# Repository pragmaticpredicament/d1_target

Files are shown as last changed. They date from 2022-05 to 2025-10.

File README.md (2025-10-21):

This repo documents an inexpensive reactive and dynamic target system, with a configurable and easy to use interface.

Demo 1

Demo 2

The d1 mini is ideally suited to this task
* cheap
* built in wifi (for target communications)
* enough i/o pins for 2 sets of leds
* enough i/o drive current for daylight bright leds without additional driver components

# Bill of materials (per target)
### power supply:
* 2xaa battery box - https://www.ebay.com/itm/274488658276
* ~~usb pigtail (to plug into d1 mini) - https://www.ebay.com/itm/193849305502~~ (I just directly solder the boost converter to the d1 mini now, bypassing this point of failure)
* boost converter (to convert to 5v) - https://www.ebay.com/itm/143853151565

### target:
* WeMos D1 Mini ESP8266 Arduino WiFi Board
* ADXL345 accelerometer - https://www.ebay.com/itm/114721937607
* common annode 4 color leds (clear seems brighter head on vs diffuse, common annode allows more current)- ~~https://www.ebay.com/itm/274488658276~~ I just search "5MM 4pin Common Anode Water Clear RGB" on ebay
* resistors (I chose 100 ohms for red, 220 ohms for green, and 50 ohms for blue)
* ~~connectors to make replacing broken leds easier (I used 4 pin jst sm connectors) - https://www.ebay.com/itm/274534656436~~ (I have stopped using these, I just hardwire all leds now. They haven't proven to be worth the hassle)
* extra wire, solder, heat shrink etc.. to connect everything together

### additional:
* wifi router ( i use GL.iNet GL-AR300M16-Ext https://www.amazon.com/dp/B07794JRC5)
* smartphone/computer to connect to targets and run game

# Build Instructions

### Wiring Diagram:
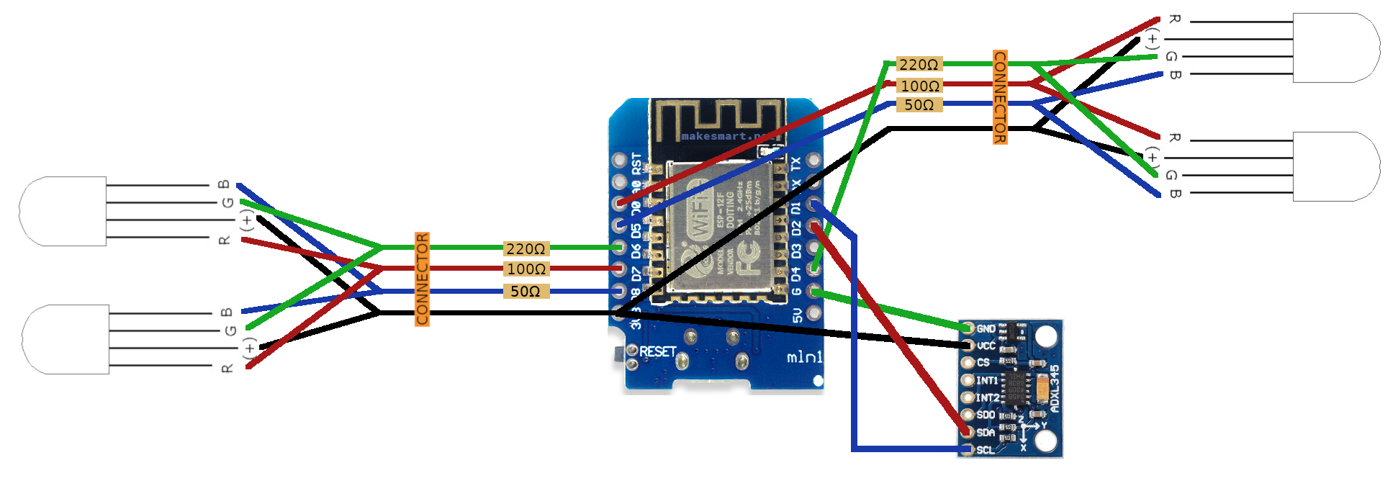
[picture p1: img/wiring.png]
Wiring Diagram


### Assembly:
You can arrange your components however you want. It was convenient for me to attach the d1 mini and the boost converter to the battery conatiner:

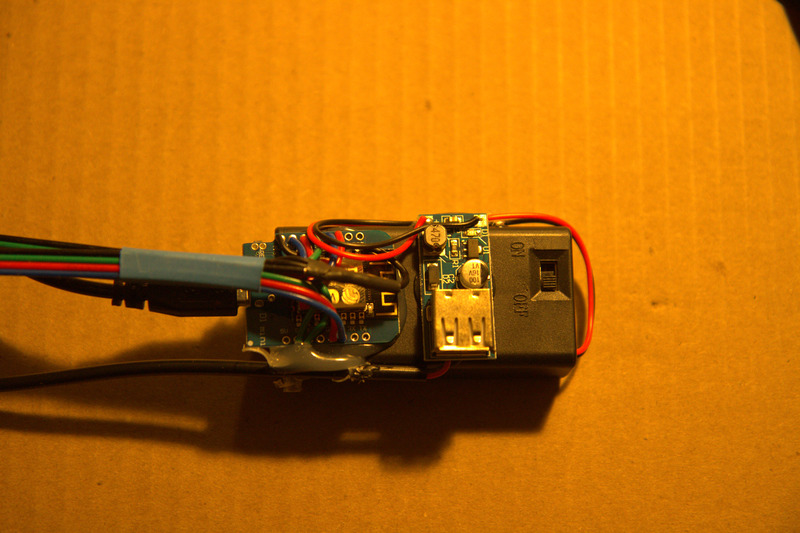
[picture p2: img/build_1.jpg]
Build 1

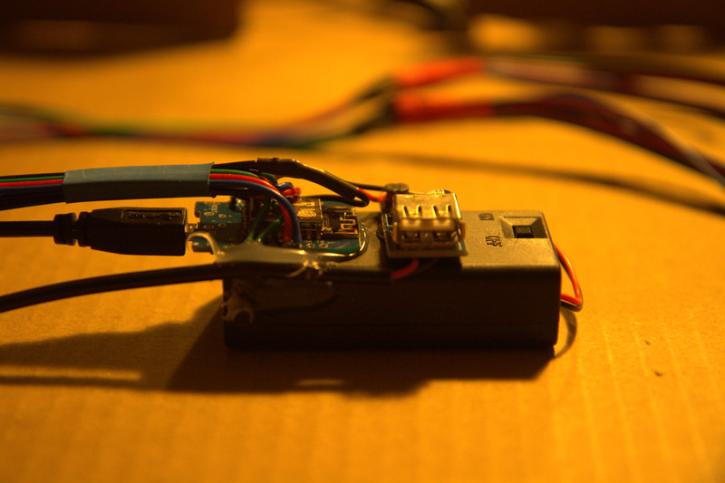
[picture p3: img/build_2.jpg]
Build 2

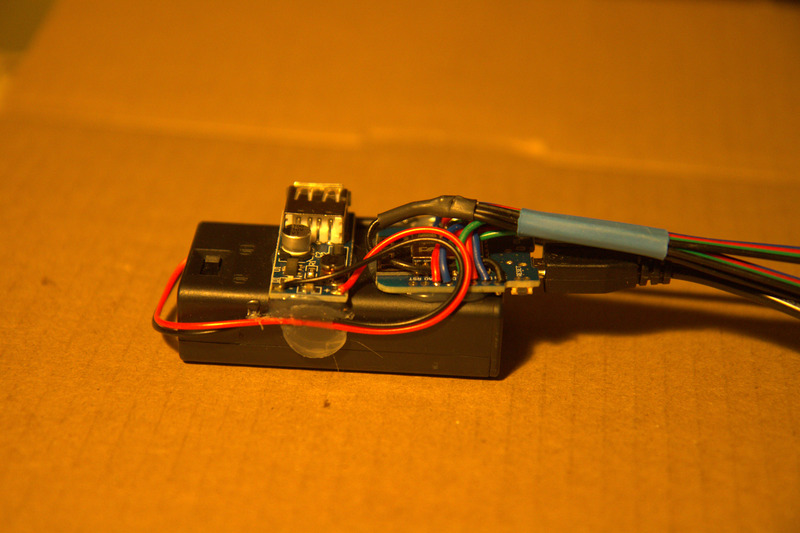
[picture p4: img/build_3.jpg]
Build 3


I left the leds and accelerometers a bit long 

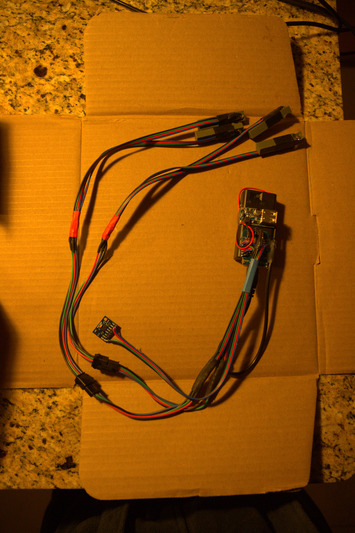
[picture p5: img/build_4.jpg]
Build 4


I use these little led brackes to help secure the leds.
* led_bracket.stl in /stl 
* I manually drilled them out with a 1/8 drill for the leds to fit

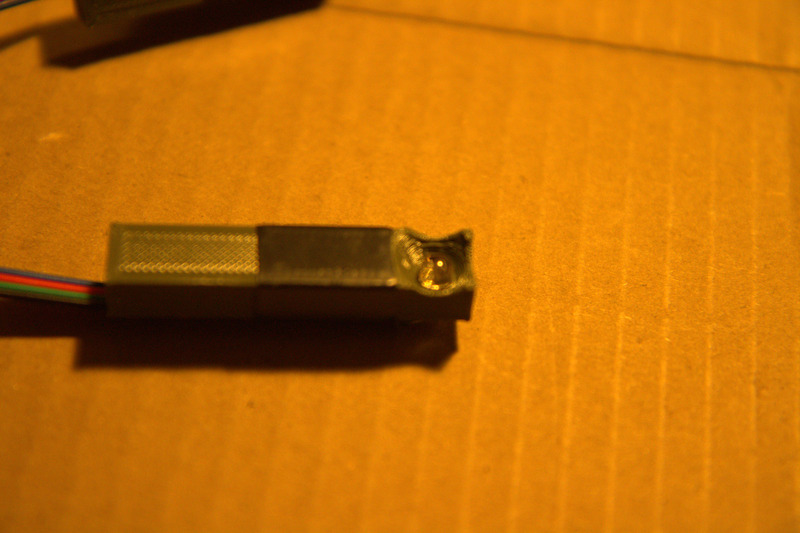
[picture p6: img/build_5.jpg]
Build 5

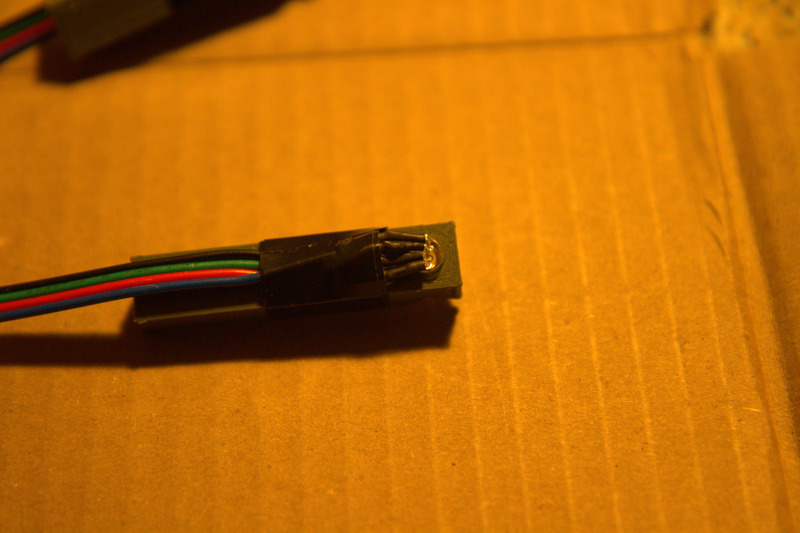
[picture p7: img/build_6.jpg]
Build 6


Here you can see how they are attached to the target, with the accelerometer taped to the center, and the leds just slightly protruding

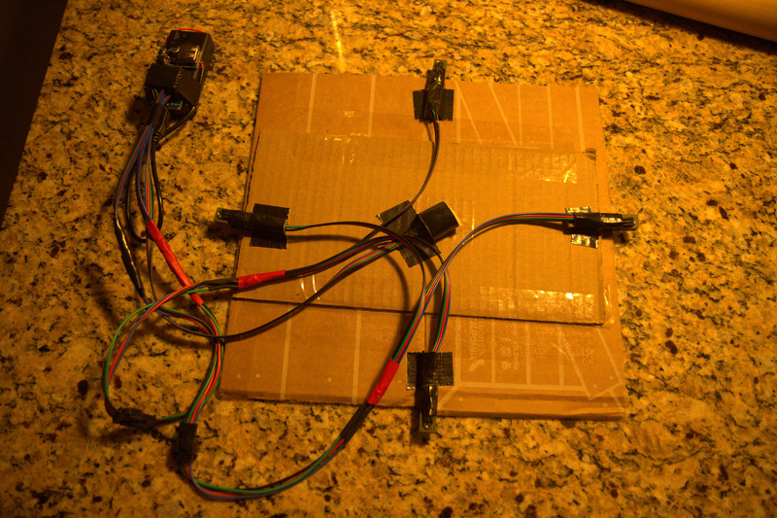
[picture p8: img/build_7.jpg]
Build 7


# Ide setup:

### Arduino/d1 mini setup: https://gist.github.com/carljdp/e6a3f5a11edea63c2c14312b534f4e53
* install latest arduino release https://www.arduino.cc/en/software/OldSoftwareReleases (or use ubuntu software repo)
* add board manager url: File -> preferences -> Additional Boards Manager URLs : http://arduino.esp8266.com/stable/package_esp8266com_index.json
* install d1 mini board: Tools -> Board:* -> Boards Manager... : install esp8266 (3.0.2 at time of writing)
* select d1 mini board: Tools -> Board:* -> ESP8266 Boards (3.0.2) -> LOLIN(WEMOS) D1 mini (clone)
* plug in d1 mini
* update port: Tools -> Port
* you can test this part of the setup by running the blink sketch, described in the above linked walkthrough

### adxl345 setup: https://www.teachmemicro.com/use-adxl345-arduino/
* from Tools -> Manage Libraries..., install “Adafruit ADXL345” (1.3.1 at time of writing), install all dependencies

### filesystem uploader: https://randomnerdtutorials.com/install-esp8266-filesystem-uploader-arduino-ide/
* unzip https://github.com/esp8266/arduino-esp8266fs-plugin/releases into tools folder
* for ubuntu repository arduino install, path was ~/snap/arduino/61/Arduino/tools/ESP8266FS/tool/esp8266fs.jar 
* for installing arduino outside of repository, path was ~/Arduino/arduino-1.8.15/tools/ESP8266FS/tool/esp8266fs.jar
* your path may be different, you can find the genral location from File -> Preferences : Sketchbook Location
You must restart arduino for the uploader to show up 
* uploader will be at Tools -> ESP8266 Sketch Data Upload

### Your IDE environment is now set up

# Send software to d1 mini:
* The project folder (git checkout dir) must be named d1_target
* In the Arduino IDE, Open d1_target.ino (the parent folder must also be named d1_target)
* Click Verify (Check mark below File)
* Click Upload (Right Arrow below Edit)
* Upload website data to d1 mini: Tools -> ESP8266 Sketch Data Upload (make sure any serial monitors are closed)

### d1 target software should now be on the d1 mini

# Wifi router setup
* the default ssid that the d1 mini targets will try to connect to is "TARGET_NET", and the password is "d1miniii"
  * you should set your router to those parameters, or update the parameters "ssid" and "wpass" in d1_target.ino (and then re upload) 
* targets are detected basically by a ping sweep, so limiting the dhcp address range helps if possible
* having a portable router that can run off a usb battery pack helps if you are moving your targets outside of the house

# Testing

### Obtain IP Address:
* when the target is able to connect to wifi, and get an ip address, all 4 leds will turn green (and stay green until given another command)
* you need to obtain the ip address of your d1 mini. this can be done in several ways:
  * you can use the arduino serial monitor (Tools -> Serial Monitor, use 115200 baud) then plug the target into your usb cable.  after the target boots up and gets an ip connection, it will output the ip address
  * use your wifi router interface to find the ip address from a client list
  * manually start testing ip addresses starting at your router's dhcp address range

### Run a blink command:
* `curl 'http://<ip address>/blink?count=3&on=500&off=500&color=r'`
  * All 4 leds should blink red 3 times
* `curl 'http://<ip address>/blink?count=3&on=500&off=500&color=g'`
  * All 4 leds should blink green 3 times
* `curl 'http://<ip address>/blink?count=3&on=500&off=500&color=b'`
  * All 4 leds should blink blue 3 times
* `curl 'http://<ip address>/blink?count=3&on=500&off=500&color=w'`
  * All 4 leds should blink white 3 times
* curl command should return `{"blinked":true}`

### Run a target command
* `curl 'http://<ip address>/target?x=20&y=20&z=20&duration=10000'`
  * All 4 leds should turn blue for 10 seconds (duration value=milliseconds) then turn red
  * your curl command should return something like this:
`{"x":0,"y":0,"z":0,"hit_time":0.00,"hit_interval":0,"max_interval":1552,"sample_interval":1250,"samples":8002,"expected_samples":8001}`
  * x, y, and z are the maximum g force (in 10ths of a g) that was experienced by the accelerometer during the target command

### Interact with target: 
* `curl 'http://<ip address>/target?x=20&y=20&z=20&duration=10000'`
  * All 4 leds should turn blue. Flick the accelerometer within 10 seconds (duration = milliseconds), All leds should turn green
  * Your curl command should return something like this:
`{"x":10,"y":9,"z":73,"hit_time":874.00,"hit_interval":1249,"max_interval":1531,"sample_interval":1250,"samples":701,"expected_samples":700}`
  * x, y, and z should be nonzero, and scale relative to how hard the accelerometer was flicked

### Load Web UI

### If all of these work, you can safely assume that this target is tested working

# Gameplay:

### Load the game interface in a web browser
* You will need to open a web browser on your smartphone, laptop, etc.. that is connected to the same network as the target.
* go to one of the addresses of your targets.  Each target will have the web page code, so you only need to find one of them.
  * I personally just manually type in the first address of the dhcp range I have set up in my router, then manually increment until I hit one.
  * You can also find the ip of one of the targets by connecting it to the serial arduino monitor

## There are 3 sections of the ui:

### Target Setup
The first section of the UI detects the targets.

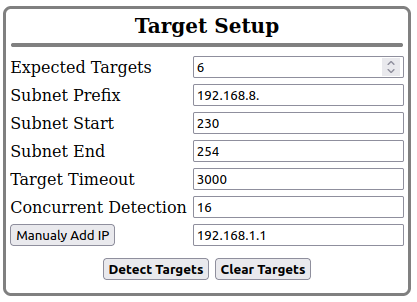
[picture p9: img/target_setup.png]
Target Setup


* Expected Targets: This represents how many targets you expect to be detected (how many are currently on, with green lights indicating they have an ip address)
* Subnet Prefix/Subnet Start/Subnet End: this defines the range to be scanned for targets
  * In this case we will scan 192.168.8.230 - 192.168.8.854
  * This should generally correspond with the dhcp address range you have configured on your wifi router
* Target Timeout: How long to wait for each target to respond
* Concurrent Detection:  How many targets should be pinged at a time
* Manually Add IP: If you want to manually type in ip addresses
* Detect Targets: Scan the ip address range above using the timeouts, and add targets as they respond
* Clear Targets: Clear any targets that have been found

Once target detection or manual addition is complete, you should see the targets listed

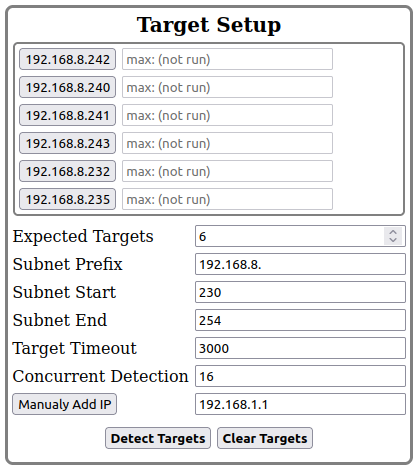
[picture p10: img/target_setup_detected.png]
Target Setup Detected


* Each ip address is a clickable button that will cause the corresponding target to light up blue for 3 seconds, then return the maximum g force the target experienced while light.

### Stage Setup
Your gameplay consists of multiple actions linked together to form a stage. You can use the plus and minus buttons to add or remove actions.

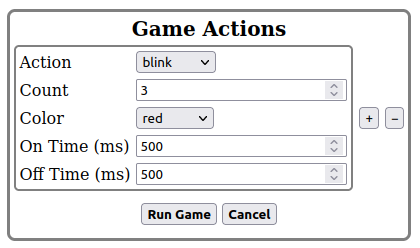
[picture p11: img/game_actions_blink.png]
Game Actions Blink


Action: Blink - This action will blink all targets, at the same time, with the specified parameters.
* Count: The number of times each target should blink
* Color: The color of the leds that should be set during the blinks
* On Time (ms): The amount of time each led should stay on per blink, in milliseconds
* Off Time (ms): The amount of time each led should stay off per blink, in milliseconds

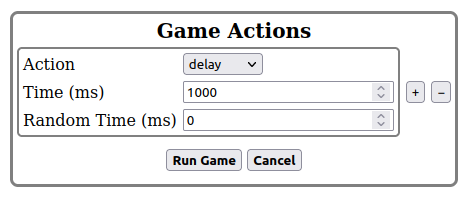
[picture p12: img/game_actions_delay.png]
Game Actions Delay


Action: Delay - This action will insert a delay between other actions equal to (Time + (between 0 and Random Time)) milliseconds.
* Time (ms): The amount of time that this action will delay
* Random Time (ms): An additional maximum random delay added to the fixed above delay (random value between 0 and this value)

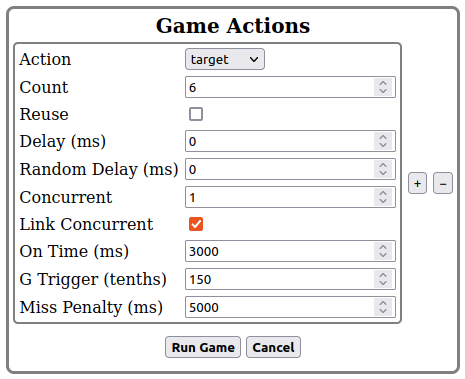
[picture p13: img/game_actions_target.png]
Game Actions Target


Action: Target - this causes targets to be available to be hit
* Count: The total number of targets that will be available to be hit during this action
* Reuse: If a target can be light more than once during this action
  * targets are picked randomly, if reuse is enabled, then a target, once light, will go back into the random selection pool
  * if not enabled, only min(count, existant targets) can be light, because the random target selector will not consider a target again after it has been light
* Delay (ms): The delay between each target being light and available to be hit.
* Random Delay (ms): An additional maximum random delay (random value between 0 and this value)
* Concurrent: How many targets to light concurrently
* Link Concurrent: Should all concurrent targets have to be hit before new targets can be light
* On Time (ms): Amount of time the target will be light before either being hit, or considered a failure
* G Trigger (tenths): How hard you need to hit the target to register (140 = 14.0 g)
* Miss Penalty (ms): How much time should be added to your score should you fail to hit the target in the alloted time 

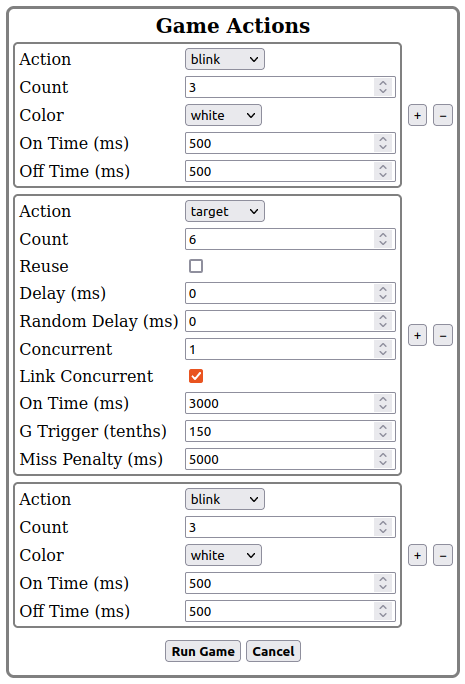
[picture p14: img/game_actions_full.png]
Game Actions Full


Here is our sample game:
* We blink white 3 times, to indicate to the player that the stage is beginning
* Each of our 6 targets will be light once, in a random ordering
  *The Player gets 3 seconds to hit the target before it is considered a failure

The target UI works as such:
* A target lights up blue, indicating that it is available to be hit
* If the target is hit before the time limit expires, the target turns green, and another target is light (if any more are available)
* If the target expires before being hit, the target turns red, and another target is light (if any more are available)

## Game Results
Game results are broken down into sections. 
* The first section is the overall summed results of all target actions
* Subsequent sections give the results of each action individually

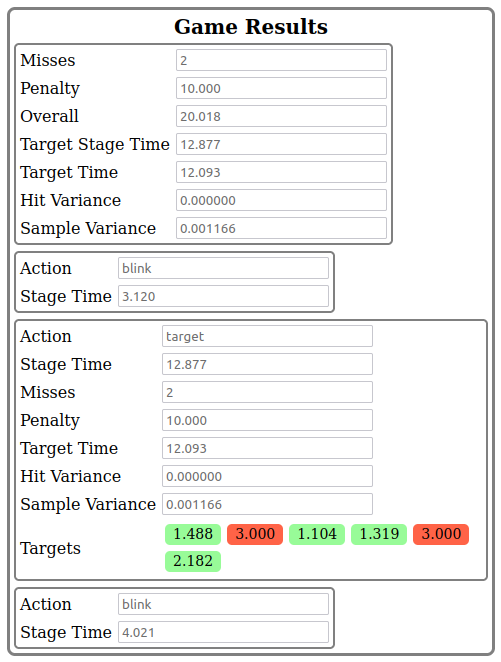
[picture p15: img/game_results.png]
Game Results


### Target Actions Summary
* Misses: The total misses of all target actions
* Penalty: The total penalties accrued over all target actions 
* Overall: The total time to complete all actions
* Target Stage Time: The total time to complete all target actions
* Target Time: The total time that each target was blue, before being hit or timing out (as measured on the target)
  * In my opinion this is the most fair and valuable score, as it is not effected by any network latency
* Hit Variance: This is mostly a debug parameter.  It indicates the maximum time error during the iteration on the d1 mini during which the hit was detected
* Sample Variance: This is mostly a debug parameter.  It indicates the sumation of all time error on sampling intervals for the d1 min.
  * Time error exists in this project as the d1 mini requires the programmer to yeild time to it to handle the tcp/ip stack, and this time is non deterministic. 

### Individual Actions 
* For blink and delay actions, these just display the time information that each action consumed
* For target actions, the metrics are similar to the summary above, with the addition of timing information for each individual target.

# Design notes
The d1 mini i/o pins are documented to provide 12ma max, however it supposedly can provide up to 15ma if you use the i/o pins to provide grounds to the leds, which is why I use common annode leds 

Here is the led characterization i got for various resistor configurations using the d1 mini i/o output voltage (for ~~https://www.ebay.com/itm/274488658276~~ search "5MM 4pin Common Anode Water Clear RGB" on ebay)
I tested both single leds, and 2 leds in parallel (which is the configration used in this project

|Leds in parallel|resistor ohms|Red ma|Green ma|Blue ma|
|---|---|---|---|---|
|1|50|13|7|6|
|1|100|23|11|10|
|1|220|7|4|4|
|2|50|26|14|12|
|2|100|14|9|7|
|2|220|7|5|4|

For 2 leds in parallel, the following resistor values provided the maximum output, while staying under the maximum 15ma current, and appearing of similar brightness
* red: 100 ohms
* green: 220 ohms
* blue: 50 ohms

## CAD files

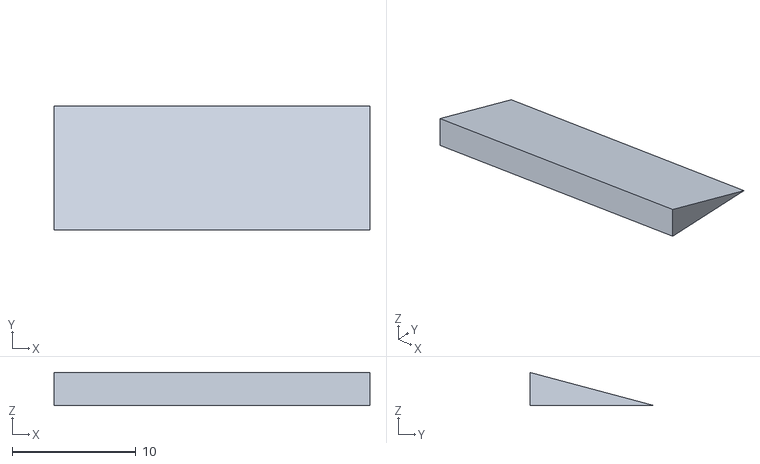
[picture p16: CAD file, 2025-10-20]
stl/15_degree_wedge.stl
25.5 x 10.0 x 2.67

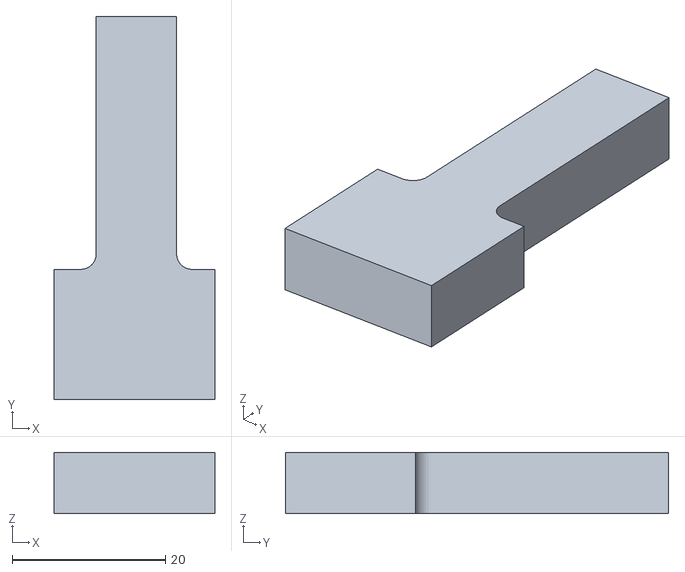
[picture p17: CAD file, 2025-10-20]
stl/accelerometer_strain_relief.stl
21.0 x 50.0 x 8.00

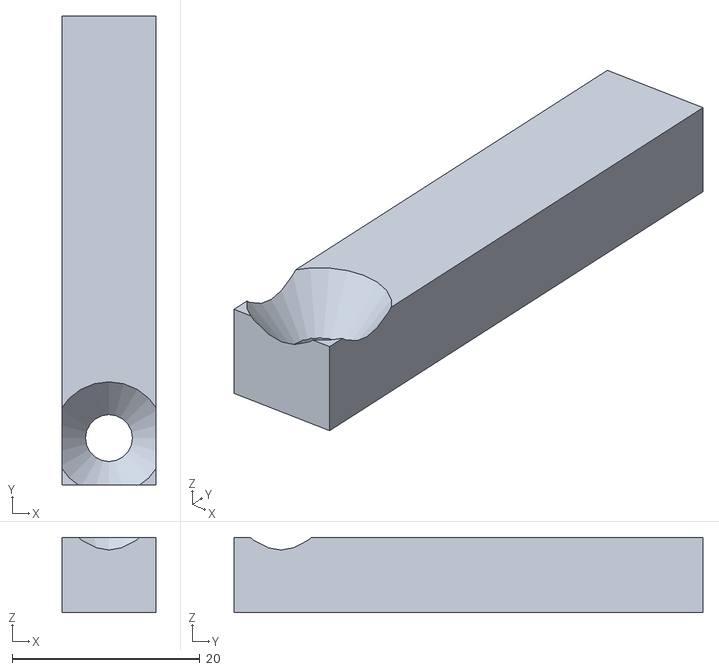
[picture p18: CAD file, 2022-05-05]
stl/led_bracket.stl
10.0 x 50.0 x 8.00

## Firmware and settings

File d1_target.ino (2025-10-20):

#include <ESP8266WiFi.h>
#include <ESP8266WebServer.h>
#include <Adafruit_ADXL345_U.h>
#include <Wire.h>
#include <FS.h>

const String version = "0.3.0";

typedef unsigned long micro_t;

Adafruit_ADXL345_Unified accel = Adafruit_ADXL345_Unified(12345);

ESP8266WebServer server(80);

const String ssid = "TARGET_NET";
const String wpass = "d1miniii"; //password 8 chars
const String wmode = "infra";

IPAddress local_IP(192,168,4,205);
IPAddress gateway(192,168,4,1);
IPAddress subnet(255,255,255,0);

#define LED_RED_1	  D0
#define LED_RED_2	  D7
#define LED_GREEN_1 D4
#define LED_GREEN_2 D6
#define LED_BLUE_1  D5
#define LED_BLUE_2  D8

void setLed(char c){
	digitalWrite(LED_BUILTIN, (c=='a' || c=='i') ? LOW : HIGH);
	
	if(c=='a'){
		c='w';
	}
	
	//'w' = white
	if(c=='w' || c=='r'){
		digitalWrite(LED_RED_1, LOW);
		digitalWrite(LED_RED_2, LOW);
	}else{
		digitalWrite(LED_RED_1, HIGH);
		digitalWrite(LED_RED_2, HIGH);
	}
	
	if(c=='w' || c=='g'){
		digitalWrite(LED_GREEN_1, LOW);
		digitalWrite(LED_GREEN_2, LOW);
	}else{
		digitalWrite(LED_GREEN_1, HIGH);
		digitalWrite(LED_GREEN_2, HIGH);
	}
	
	if(c=='w' || c=='b'){
		digitalWrite(LED_BLUE_1, LOW);
		digitalWrite(LED_BLUE_2, LOW);
	}else{
		digitalWrite(LED_BLUE_1, HIGH);
		digitalWrite(LED_BLUE_2, HIGH);
	}
}

//all
//internal
//white
//red
//green
//blue
void setLed(const String &s){
	if(s.isEmpty()){
		setLed('x');
	}
	setLed(tolower(s[0]));
}

void blinkLed(int count, int on, int off, String color){
	for(int i=0;i<count;++i){
		setLed('x');
		delay(off);
		setLed(color);
		delay(on);
	}
	setLed('x');
}

void handleBlink() {
	int blink_count=0;
	int blink_on=500;
	int blink_off=500;
	String blink_color="green";
	
	if(server.hasArg("count")){
		blink_count=server.arg("count").toInt();
	}
	if(server.hasArg("on")){
		blink_on=server.arg("on").toInt();
	}
	if(server.hasArg("off")){
		blink_off=server.arg("off").toInt();
	}
	if(server.hasArg("color")){
		blink_color=server.arg("color");
	}
	
	blinkLed(blink_count, blink_on, blink_off, blink_color);

	String json = "{\"blinked\":true,\"v\":\"" + version + "\"}\n";
	server.sendHeader("Access-Control-Allow-Origin", "*");
	server.send(200, "application/json", json);
}

void handleTarget() {
	float x_trigger = 40;
	float y_trigger = 40;
	float z_trigger = 40;
	int x_value = 0;
	int y_value = 0;
	int z_value = 0;
	micro_t run_duration = 1000000; //how long is the target available to be hit
	micro_t sample_interval = ceil(1000000 / 800);
	int sample_count = 0;
	int result_show = 1000; //time to show hit result/timeout (red/green)
	bool noshoot = false;
	int light_duration = run_duration; //how long led will be light (target may be hit after light goes out if run_duration > light_duration)
	String color = "blue";
	
	if(server.hasArg("duration")){
		run_duration=server.arg("duration").toInt()*1000;
		light_duration=run_duration;
	}
	if(server.hasArg("light")){
		light_duration=server.arg("light").toInt()*1000;
	}
	if(server.hasArg("noshoot")){
		noshoot = true;
	}
	if(server.hasArg("result_show")){
		result_show=server.arg("result_show").toInt();
	}
	if(server.hasArg("color")){
		color=server.arg("color");
	}
	if(server.hasArg("g")){
		x_trigger=y_trigger=z_trigger=server.arg("g").toFloat();
	}
	if(server.hasArg("x")){
		x_trigger=server.arg("x").toFloat();
	}
	if(server.hasArg("y")){
		y_trigger=server.arg("y").toFloat();
	}
	if(server.hasArg("z")){
		z_trigger=server.arg("z").toFloat();
	}
	
	sensors_event_t event;
	micro_t rollover_addition = 0;
	micro_t start = micros();
	micro_t last = start;
	micro_t bucket = start / sample_interval;
	micro_t hit_time = 0;
	micro_t hit_interval = 0;
	micro_t max_interval = 0;
	
	setLed(color);
	while(true){
		micro_t curr = micros();
		accel.getEvent(&event);
		++sample_count;
		if(curr < start){
			rollover_addition = std::numeric_limits<micro_t>::max() - start;
			start = 0;
		}
		micro_t curr_offset = (curr - start) + rollover_addition;
		if( (curr_offset/1000) > light_duration ) {
			setLed('x');
		} 
		bucket = curr / sample_interval;
		
		if(abs(event.acceleration.x) > x_trigger
					|| abs(event.acceleration.y) > y_trigger
					|| abs(event.acceleration.z) > z_trigger ){
			hit_time= curr_offset;
			if(curr < last){
				 hit_interval = curr + (std::numeric_limits<micro_t>::max()-last);
			}else{
				 hit_interval = curr-last;
			}
			
			x_value = abs(floor(event.acceleration.x));
			y_value = abs(floor(event.acceleration.y));
			z_value = abs(floor(event.acceleration.z));
			break;
		}
		if(curr < last){
			max_interval = max(max_interval,curr + (std::numeric_limits<micro_t>::max()-last));
		}else{
			max_interval = max(max_interval,curr-last);
		}
		last = curr;
		
		if(((curr-start)+rollover_addition) >= run_duration){
		 	break;
		}
		
		yield(); //let esp8266 handle tcp/wifi
		curr = micros();
		if(curr < start){
			rollover_addition = std::numeric_limits<micro_t>::max() - start;
			start = 0;
		}

		micro_t curr_bucket = curr / sample_interval;
		if(curr_bucket == bucket){
			delayMicroseconds(sample_interval - curr%sample_interval);
		}
		bucket = micros() / sample_interval;
	} 
	String json;
	json += "{\"x\":" + String(x_value) + ",";
	json += "\"y\":" + String(y_value) + ",";
	json += "\"z\":" + String(z_value) + ",";
	json += "\"v\":\"" + version + "\",";
	json += "\"hit_time\":" + String(floor(hit_time/1000)) + ",";
   json += "\"hit_interval\":" + String(hit_interval) + ",";
	json += "\"max_interval\":" + String(max_interval) + ",";
	json += "\"sample_interval\":" + String(sample_interval) + ",";
	json += "\"samples\":" + String(sample_count) + ",";
	json += "\"expected_samples\":" + String((micros()-start)/sample_interval) + "}\n";
	server.sendHeader("Access-Control-Allow-Origin", "*");
	server.send(200, "application/json", json);
	if(noshoot){
		if(hit_time == 0){
			setLed('x');
		}else{
			blinkLed(5, result_show/10, result_show/10, "red");
		}
	}else{	
		if(hit_time == 0){
			blinkLed(5, result_show/10, result_show/10, "red");
		}else{
			blinkLed(5, result_show/10, result_show/10, "green");
		}
	}
	delay(result_show);
	setLed('x');
}

void handleMaxG() {
	int run_duration = 1000000;
	int sample_interval = ceil(1000000 / 800);
	int sample_count = 0;
	bool console = false;
	
	if(server.hasArg("duration")){
		run_duration=server.arg("duration").toInt()*1000;
	}
	if(server.hasArg("console")){
		console = true;
	}
	
	sensors_event_t event; 
	float max_x = 0;
	float max_y = 0;
	float max_z = 0;

	micro_t rollover_addition = 0;
	micro_t start = micros();
	micro_t last = start;
	micro_t max_interval = 0;
	micro_t bucket = start / sample_interval;
		
	setLed('b');
	while(true){
		micro_t curr = micros();
		accel.getEvent(&event);
		++sample_count;
		if(curr < start){
			rollover_addition = std::numeric_limits<micro_t>::max() - start;
			start = 0;
		}
		bucket = curr / sample_interval;
		
		if(curr < last){
			max_interval = max(max_interval,curr + (std::numeric_limits<micro_t>::max()-last));
		}else{
			max_interval = max(max_interval,curr-last);
		}
		last = curr;
		
		max_x = max(max_x,abs(event.acceleration.x));
		max_y = max(max_y,abs(event.acceleration.y));
		max_z = max(max_z,abs(event.acceleration.z));
		
		if(console){
			Serial.print(micros()); 
			Serial.print(" x:");
			Serial.print(String(event.acceleration.x,3));
			Serial.print(" y:");
			Serial.print(String(event.acceleration.y,3));
			Serial.print(" z:");
			Serial.print(String(event.acceleration.z,3));
			Serial.println(); 
		}
		
		if(((curr-start)+rollover_addition) >= run_duration){
		 	break;
		}
		
		yield();	//let esp8266 handle tcp/wifi
		curr = micros();
		if(curr < start){
			rollover_addition = std::numeric_limits<micro_t>::max() - start;
			start = 0;
		}
				
		micro_t curr_bucket = curr / sample_interval;
		if(curr_bucket == bucket){
			delayMicroseconds(sample_interval - curr%sample_interval);
		}
	} 
	String json;
	json += "{\"x\":" + String(floor(max_x)) + ",";
	json += "\"y\":" + String(floor(max_y)) + ",";
	json += "\"z\":" + String(floor(max_z)) + ",";
	json += "\"v\":\"" + version + "\",";
	json += "\"max_interval\":" + String(max_interval) + ",";
	json += "\"sample_interval\":" + String(sample_interval) + ",";
	json += "\"samples\":" + String(sample_count) + ",";
	json += "\"expected_samples\":" + String(run_duration/sample_interval) + "}\n";
	setLed('x');
	server.sendHeader("Access-Control-Allow-Origin", "*");
	server.send(200, "application/json", json);
}

void handleChangeNetwork(){
	String type = "infrastructure"; //or ad-hoc
	String hostname = "opentarget";
	String ssid;
	String password;

	if(server.hasArg("type")){
		type=server.arg("type");
	}
	if(server.hasArg("hostname")){
		hostname=server.arg("hostname");
	}
	if(server.hasArg("ssid")){
		ssid=server.arg("ssid");
	}
	if(server.hasArg("password")){
		password=server.arg("password");
	}

	if(type == "infrastructure"){
		WiFi.mode(WIFI_STA);
		if(!hostname.isEmpty()){
			WiFi.hostname(hostname);
		}
		WiFi.begin(ssid, password);
		while (WiFi.status() != WL_CONNECTED) {
			delay(500);
			Serial.print(".");
		}
		Serial.print("infrastructure ip: ");
		Serial.println(WiFi.localIP()); 
	} else if (type == "ad-hoc" || type == "adhoc") {
		WiFi.softAP(ssid, password, 1, false, 8); //ssid, password, channel, hidden, max connections (8 is max)
		if(!hostname.isEmpty()){
			WiFi.hostname(hostname);
		}
		while (WiFi.status() != WL_CONNECTED) {
			delay(500);
			Serial.print(".");
		}
		Serial.print("ad-hoc ip: ");
		Serial.println(WiFi.softAPIP());
	}
}

void setup() 
{
	pinMode(LED_BUILTIN, OUTPUT);
	pinMode(LED_RED_1,   OUTPUT);
	pinMode(LED_RED_2,   OUTPUT);
	pinMode(LED_GREEN_1,	OUTPUT);
	pinMode(LED_GREEN_2,	OUTPUT);
	pinMode(LED_BLUE_1,  OUTPUT);
	pinMode(LED_BLUE_2,  OUTPUT);

	setLed('w');
	delay(1000);
	setLed('x');

	Serial.begin(115200);

	if(!accel.begin())
	{
		Serial.println("No ADXL345 detected");
		return;
	}
	
	if (!SPIFFS.begin()) //mount the file system
	{
		Serial.println("Failed to mount file system");
		return;
	}

	accel.setRange(ADXL345_RANGE_16_G);
	// accel.setRange(ADXL345_RANGE_8_G);
	// accel.setRange(ADXL345_RANGE_4_G);
	// accel.setRange(ADXL345_RANGE_2_G);
	
	//accel.setDataRate(ADXL345_DATARATE_1600_HZ);
	accel.setDataRate(ADXL345_DATARATE_800_HZ);
	//accel.setDataRate(ADXL345_DATARATE_400_HZ);
	//accel.setDataRate(ADXL345_DATARATE_200_HZ);
	//accel.setDataRate(ADXL345_DATARATE_200_HZ);

	setLed('r');
	delay(1000);
	setLed('g');
	delay(1000);
	setLed('b');
	delay(1000);
	setLed('w');
	delay(1000);
	setLed('x');

	WiFi.hostname("shootme");
	if(wmode == "infra"){
		WiFi.mode(WIFI_STA);
		WiFi.begin(ssid, wpass);
		while (WiFi.status() != WL_CONNECTED) {
			delay(500);
			Serial.print(".");
		}
		Serial.println(WiFi.localIP()); 
	}else{
		WiFi.softAPConfig(local_IP, gateway, subnet);
		WiFi.softAP(ssid, wpass, 1, false, 8);
		Serial.print("AP IP address: ");
		Serial.println(WiFi.softAPIP());
	}
 
	server.on("/target", HTTP_GET, handleTarget);
	server.on("/blink", HTTP_GET, handleBlink);
	server.on("/max", HTTP_GET, handleMaxG);
	server.on("/change", HTTP_GET, handleChangeNetwork);
	
	server.serveStatic("/", SPIFFS, "/index.html");
	server.serveStatic("/game.js", SPIFFS, "/game.js");
	server.serveStatic("/detector.js", SPIFFS, "/detector.js");
	server.serveStatic("/actions.js", SPIFFS, "/actions.js");
	server.serveStatic("/report.js", SPIFFS, "/report.js");

	server.begin();
	
	Wire.setClock(800000L);
	
	setLed('g');
}
 
void loop() {
	server.handleClient();
}

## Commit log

2022-05-05 initial add
    [led_bracket.stl]
2022-07-17 separate totals and stage breakdown more clearly in ui, fix some bugs with multiple targets
    [d1_target.ino]
2023-08-23 add comments to target parameters. change default target/count. add option to remove white from noshoot random colors (for red/green colorblind). set random if count > physical targets or noshoots en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
2025-10-20 initial white blink on startup, then cycle colors after accel initialization. if you just get a white blink, you know accel is broken
    [d1_target.ino]
2025-10-20 add stl for accel strain relief
    [accelerometer_strain_relief.stl]
2025-10-20 a wedge can be helpful if your targets don't hang perfectly vertical, to help align leds towards user
    [15_degree_wedge.stl]
